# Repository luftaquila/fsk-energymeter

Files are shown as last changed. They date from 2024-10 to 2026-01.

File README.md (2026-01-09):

# Formula Student Korea Electric Energy Meter

<p align="center">
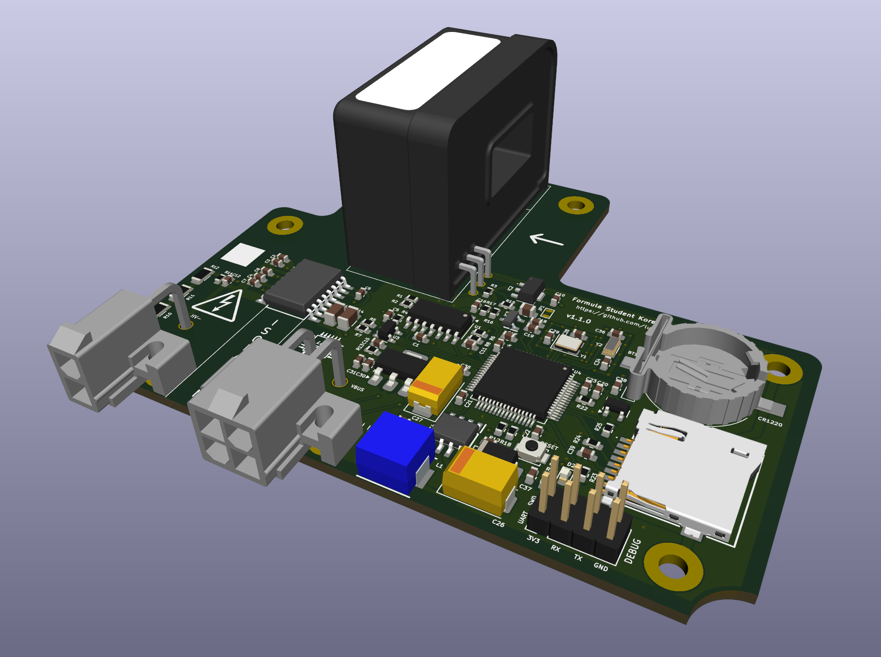
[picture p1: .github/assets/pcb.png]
  
  &ensp;
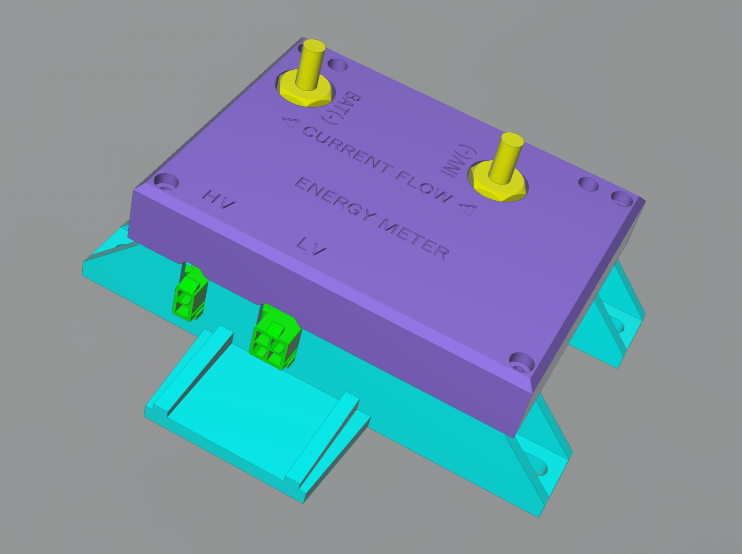
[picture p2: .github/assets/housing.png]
  
</p>

## 0. Features

* 100 Hz data recording
  * HV bus voltage 
  * HV bus current
  * LV supply voltage 
  * Ambient (CPU) temperature
  * Real-world time of each record
* USB Mass Storage data extraction
* Web-based data viewer

## 1. Specifications

| | MIN | TYP | MAX | UNIT |
|:-:|:-:|:-:|:-:|:-:|
| Supply voltage<sup>1</sup> | 6 | | 28 | V |
| Power consumption | | 0.25 | 0.5 | W |
| HV bus voltage | 0 | | 600 | V |
| HV bus voltage resolution | | 0.24 | | V/LSB |
| HV bus current | -750 | | 750 | A |
| HV bus current resolution | | 0.32 | | A/LSB |
| Operational temperature | -10 | | 80 | °C |
| IP rating | | IP 20 | | |
| Startup time | | 550 | | ms |
| Record interval | | 10 | 15 | ms |
| Possible data loss<br>on power brownout | 0 | | 100 | ms |

<sup>1</sup> When powered by USB, the device can startup with a minimum supply voltage of 4.5 V.

## 2. Connectors

> [!NOTE]
> The HV current measurement terminals at the top of the device are standard-pitch M6 brass bolts.

| | LV | HV |
|:-:|:-:|:-:|
| Model | [Molex 5569-04A1 (39291048)](https://www.molex.com/en-us/products/part-detail/39291048) | [Molex 5569-02A1 (39291028)](https://www.molex.com/en-us/products/part-detail/39291028) |
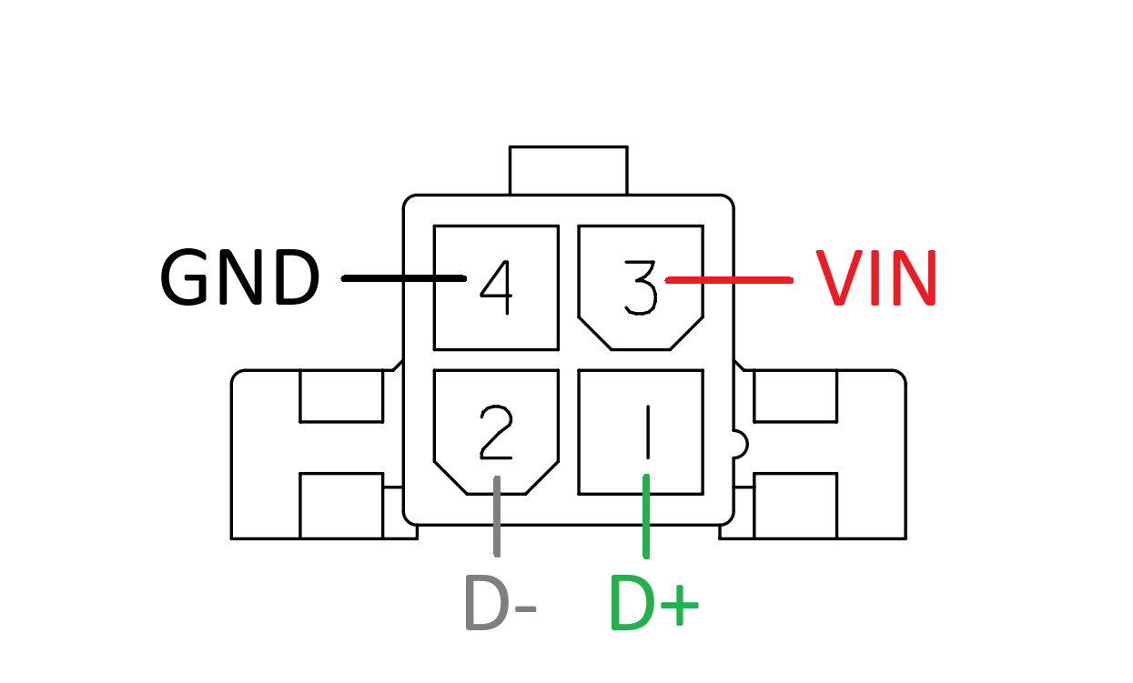
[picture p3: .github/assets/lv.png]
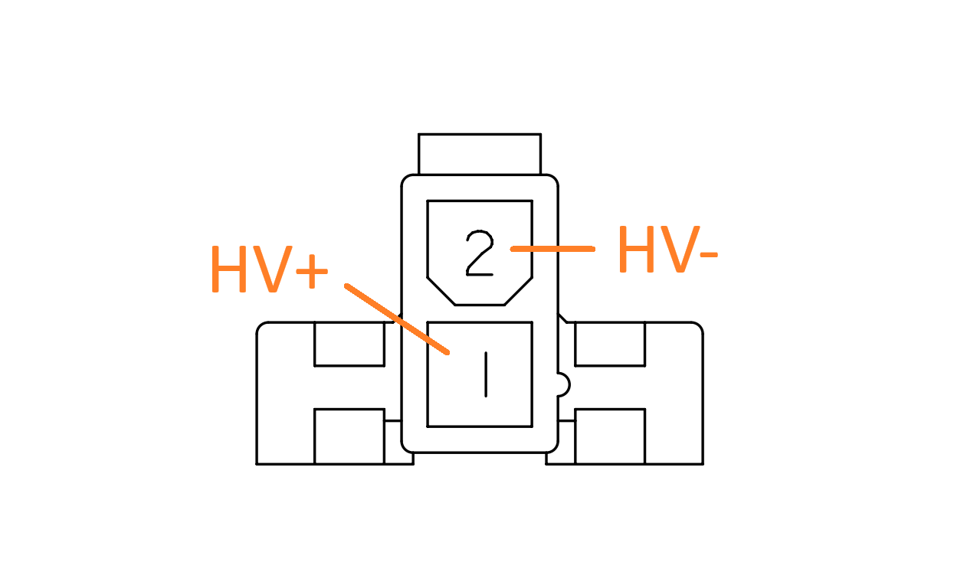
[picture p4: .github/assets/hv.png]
| Image |  |  |
| Mate | [Molex 5557-04R (39012040)](https://www.molex.com/en-us/products/part-detail/39012040) | [Molex 5557-02R (39012020)](https://www.molex.com/en-us/products/part-detail/39012020)  |
| Pinout | 1: `D+` &ensp; 2: `D-`<br>3: `VIN` &ensp; 4: `GND` | 1: `HV+` &ensp; 2: `HV-` |

> [!TIP]
> The crimp terminal for the Molex 5557 Series is [Molex 5556T (39000038)](https://www.molex.com/en-us/products/part-detail/39000038).

### Wiring

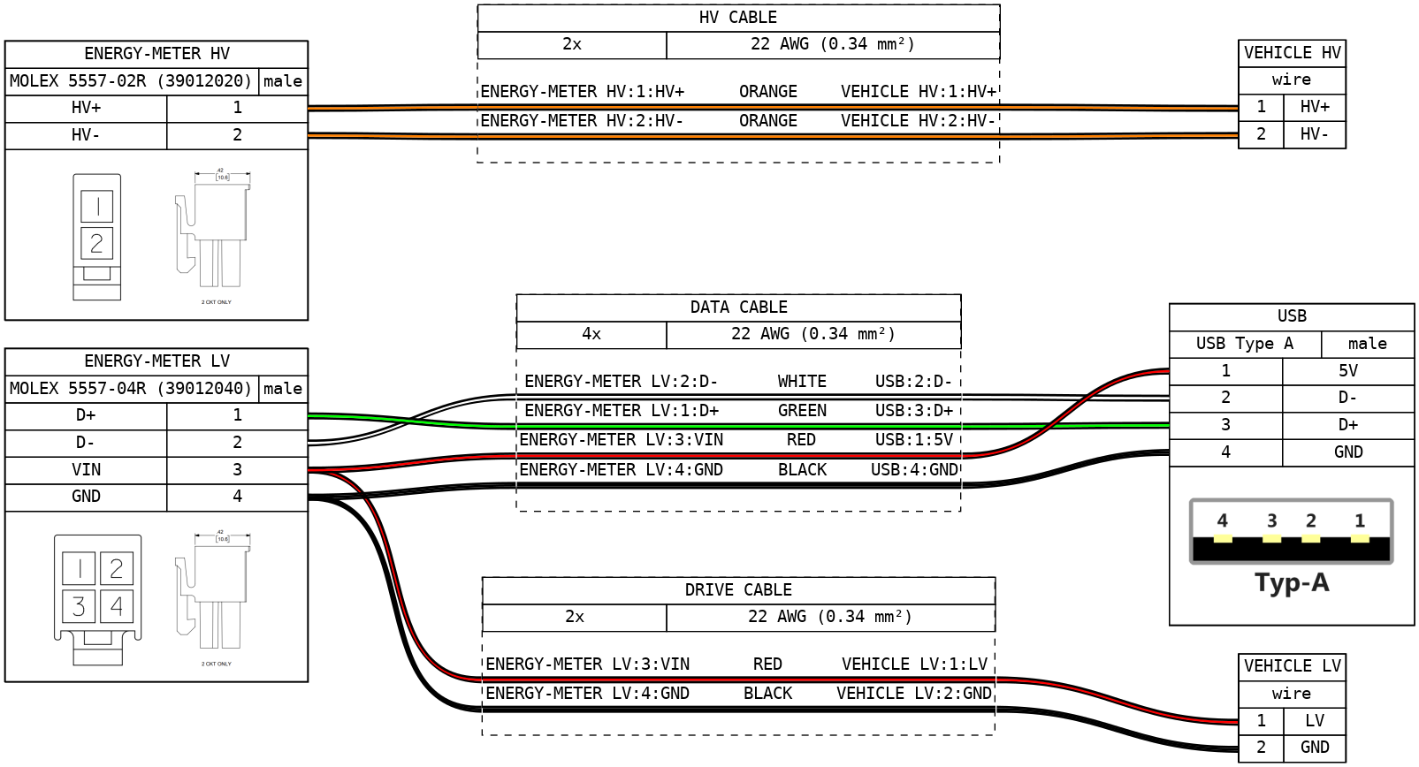
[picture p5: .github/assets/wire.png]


The _data cable_ and the _drive cable_ are two distinct cables.
When driving the vehicle, connect the _drive cable_ to the LV connector of the device.
To extract data, disconnect the _drive cable_ and connect the _data cable_ instead.

> [!CAUTION]
> Misconnection of the pins may cause permanent damage to the device.

> [!TIP]
> The easiest way to make a data cable is to cut a USB cable with Type-A connector on one end.

## 3. Usage

### 3-1. Record data

When driving the vehicle, connect both _HV cable_ and _drive cable_ to the device. The _drive cable_ should supply `VIN >= 6V` to start recording.

Once the device is powered up, it performs a zero calibration of the HV voltage and current. After calibration, it continuously measures data every 10 ms.

The measured data is updated to the file every 100 ms. During the file update, next measurement may be delayed by up to 5 ms.

A new log file is created with each power cycle. Each log file corresponds to a single power session.

> [!IMPORTANT]
> For the precise calibration, make sure that the HV voltage and current are at 0V and 0A until the startup is complete (typically 550 ms).

> [!NOTE]
> The device has an internal clock that tracks real-world time.
> Since the clock drifts over time, synchronize it with the FSK-EEM Viewer after a long period of non-use.
> If the time keeps resetting to `May 12, 2099`, the battery should be replaced.

### 3-2. Extract data

To extract the recorded data from the device, disconnect _drive cable_ and connect _data cable_ instead.
There is no need to disconnect the _HV cable_ during data extraction.

Plug the USB side of the _data cable_ to the PC or smartphone (with a Type-A to C adapter).
The FSK-EEM USB Mass Storage will appear [shortly](https://github.com/luftaquila/fsk-energymeter?tab=readme-ov-file#6-troubleshootings).

The log files are stored in the drive like a common USB memory. Copy the files to your PC.

> [!NOTE]
> The drive is ***read-only***; you cannot edit or delete the stored logs with the file explorer.

### 3-3. View data

Go to the [online viewer](https://fsk-energymeter.luftaquila.io) and open the log file to view a graph of the recorded data, or export it in a human-readable JSON/CSV format.

> [!TIP]
> If there is no Internet connection, download html or executable from the [release](https://github.com/luftaquila/fsk-energymeter/releases/latest) in advance.

### 3-4. Configure the device

In the viewer's Device Configuration section, click `Connect` and select the device to connect.

The device's UID and the current time will be displayed on successful connection.

* `Sync RTC`: Synchronizes the device clock with the host computer.
* `Delete`: Erases ***ALL*** files stored in the device.

Unplug and reconnect the device to see the change after deletion.

> [!WARNING]
> The delete action ***cannot be undone***.

## 4. DIY

### 4.1 Build hardware

1. Download `fsk-energymeter-pcb.zip` from the [latest release](https://github.com/luftaquila/fsk-energymeter/releases/latest) and extract it.
2. Place a JLCPCB PCBA (SMT) order using the GERBER, BOM and CPL files at the *gerbers/* directory.
3. Solder following parts manually to the device after the PCB arrives.
    * [L01Z600S05](https://www.eleparts.co.kr/goods/view?no=261774) Hall sensor
    * [5557-02A1](https://www.eleparts.co.kr/goods/view?no=25304) HV connector
    * [5569-04A1](https://www.eleparts.co.kr/goods/view?no=25303) LV connector
    * [2.54mm 2\*4 debug pin header](https://www.eleparts.co.kr/goods/view?no=12534585)
4. Insert the CR1220 battery and Micro SD card into the PCB.

### 4.2 Upload firmware

1. Download `fsk-energymeter-firmware.zip` from the [latest release](https://github.com/luftaquila/fsk-energymeter/releases/latest) and extract it.
1. Connect `3V3`, `GND`, `SWCLK`, `SWDIO` pins of the ST-Link to the corresponding pins on the device's debug pin header.
1. Run `flash.bat` to flash the release firmware to the device.

### 4.3 3d-print housing

1. Download `fsk-energymeter-3d.zip` from the [latest release](https://github.com/luftaquila/fsk-energymeter/releases/latest) and extract it.
2. 3d-print both `top.stl` and `bottom.stl` files.

### 4.4 Final assembly

1. Prepare 1x busbar, 2x M6 nuts, and 2x `M6*35mm` brass bolts.
    * The busbar and nuts are custom-sized and must be CNC-machined.
        * The recommended material is `C11000` copper alloy.
    * The 3D model of the busbar is at `fsk-energymeter-3d.zip`.
        * Dimensions: `75mm(L) * 12mm(W) * 6mm(H)`.
        * Distance between holes: `57.5mm` (center-to-center).
    * The nuts are standard-pitch M6 hexagonal nuts.
        * Dimensions: `14mm(W) * 16mm(H)`.
2. Prepare 5x `M3*4mm` and 4x `M3*20mm` bolts for PCB and housing assembly.
3. Insert the busbar through the Hall sensor and secure it with the M6 bolts and nuts.
4. Place the PCB-busbar assembly into the housing and assemble the housing and cover.

> [!IMPORTANT]
> The HV current path is through the M6 nuts and the busbar. The M6 bolts are not intended to carry HV current.
> Therefore, the nuts must be thick enough to handle the current and provide sufficient contact area, and tall enough to be exposed above the housing cover.

## 5. Development

> [!NOTE]
> This section is *NOT REQUIRED* in general, and is for developers who want to modify the software on their own.

<details>
<summary>click to expand</summary>

### 5-1. Firmware

#### Prerequisites

1. Clone repository
    ```sh
    git clone https://github.com/luftaquila/fsk-energymeter.git --recursive
    ```

2. Make sure the `arm-none-eabi-gcc`, `openocd` and `make` executables are in the `$PATH`.
    * Common
        * [Arm GNU Toolchain (**AArch32 bare-metal target (arm-none-eabi)**)](https://developer.arm.com/downloads/-/arm-gnu-toolchain-downloads)
    * Windows
        * [OpenOCD for Windows](https://gnutoolchains.com/arm-eabi/openocd/)
        * [Make for Windows](https://gnuwin32.sourceforge.net/packages/make.htm)
    * macOS
        ```sh
        brew install make openocd
        ```
    * Linux
        ```sh
        sudo apt-get install build-essential openocd
        ```

#### Build and upload

```sh
cd fsk-energymeter/device/firmware
make program  # release build
make debug    # debug build
```

### 5-2. Viewer

#### Prerequisites

1. [Node.js](https://nodejs.org/en/download/package-manager) >= v20
2. Clone the repository and install dependencies
    ```sh
    git clone https://github.com/luftaquila/fsk-energymeter.git --recursive
    cd fsk-energymeter/viewer
    npm install
    ```

#### Build and run

```sh 
cd fsk-energymeter/viewer
npm run dev          # development server at http://localhost:9400
npm run build        # production build for Docker image 
npm run build:dev    # production build with no base url
npm run build:single # single file html build
```

</details>

## 6. Troubleshootings

#### 1. FSK-EEM USB Mass Storage takes too long to be mounted
The device only supports USB Full Speed (USB 1.1) spec. It is decades-old technology with a maximum transfer speed of 12 Mbps.
However, in the real world, the actual speed is around 4 Mbps (0.5 MB/s).

When the device is connected to the host PC, the host will try to load the FAT table of the SDMMC.
The FAT32 FAT table is typically a few megabytes, so it will take ~20 seconds to mount.

To reduce the mount time, format SD cards with larger cluster sizes.
The RTC sync or record delete functions will work immediately regardless of this limit.

#### 2. `Web Serial API not supported` error on the FSK-EEM Viewer.

The FSK-EEM Viewer's Device Configuration tab uses the Web Serial API to talk with the device, which has [limited support](https://caniuse.com/?search=Web%20Serial%20API) across the platforms and browsers.

## 7. DISCLAIMER

> [!IMPORTANT]
> 차량기술규정 및 출력제한 위반 여부는 대회장에서 제공하는 공식 에너지미터로만 판단합니다.
> 그 밖의 에너지미터는 제조 공정의 차이 등으로 인해 공식 장치와 측정값이 상이할 수 있음을 반드시 인지해야 합니다.
> 이러한 에너지미터는 대회 중에는 사용할 수 없으며, 차량 제작 시 단순 참고용으로만 활용해야 합니다.

## 8. LICENSE

For non-commercial use only:

```
"THE BEERWARE LICENSE" (Revision 42):
LUFT-AQUILA wrote this project. As long as you retain this notice,
you can do whatever you want with this stuff. If we meet someday,
and you think this stuff is worth it, you can buy me a beer in return.
```

이 저장소의 모든 내용물은 비상업적 용도에 한해 얼마든지 자유롭게 사용할 수 있습니다.\
이 프로젝트가 마음에 든다면, 언젠가 우리가 만나게 되었을 때 맥주 한 잔 사 주세요.

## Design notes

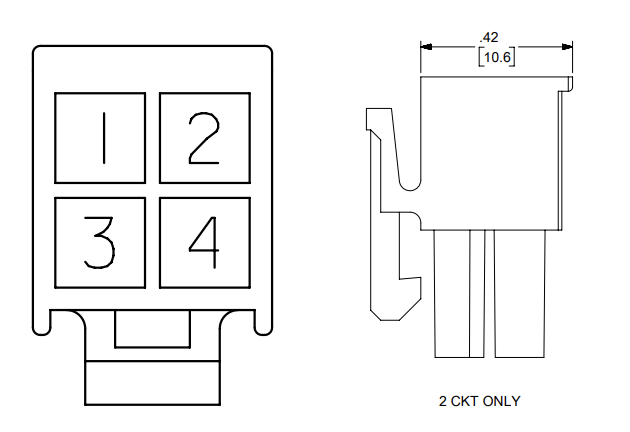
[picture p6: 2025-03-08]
.github/assets/lv-mate.png

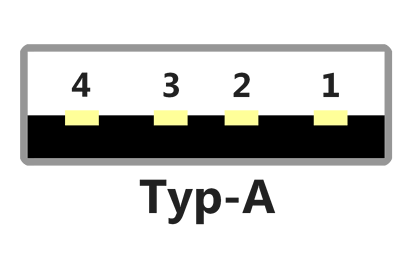
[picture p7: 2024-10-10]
.github/assets/usb.png

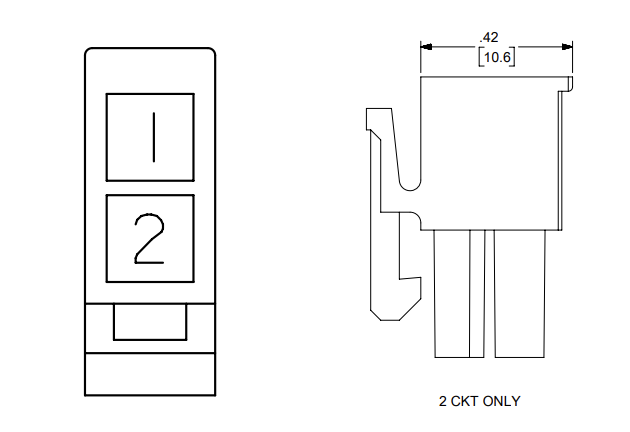
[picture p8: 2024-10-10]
.github/assets/hv-mate.png

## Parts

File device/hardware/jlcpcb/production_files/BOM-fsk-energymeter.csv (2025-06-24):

Comment | Designator | Footprint | LCSC | Quantity
LM2675MX-5.0_NOPB | IC4 | SOIC127P600X175-8N | C123126 | 1
0.1uF | C17,C21,C22,C23,C24,C30,C32,C37,C38,C39,C4,C6,C8 | C_0603_1608Metric | C14663 | 13
100pF | C12 | C_0603_1608Metric | C14858 | 1
1uF | C10,C19,C2 | C_0603_1608Metric | C15849 | 3
1nF | C3,C7 | C_0603_1608Metric | C1588 | 2
20pF | C28,C29,C34,C36 | C_0603_1608Metric | C1648 | 4
330pF | C15,C5 | C_0603_1608Metric | C1664 | 2
0.33uF | C9 | C_0805_2012Metric | C1740 | 1
1uF | C14 | C_1206_3216Metric | C1848 | 1
4.7uF | C35 | C_0603_1608Metric | C19666 | 1
22nF | C1,C11,C16 | C_0603_1608Metric | C21122 | 3
1k | R20 | R_0603_1608Metric | C21190 | 1
AMC3311QDWER | IC1 | SOIC127P1030X265-16N | C22441844 | 1
LED | D2 | LED_0603_1608Metric | C2286 | 1
2k | R1 | R_0603_1608Metric | C22975 | 1
3.3k | R13,R4,R5,R7 | R_0603_1608Metric | C22978 | 4
3.9k | R2 | R_0603_1608Metric | C23018 | 1
68k | R15 | R_0603_1608Metric | C23231 | 1
22 | R18,R19 | R_0603_1608Metric | C23345 | 2
NCP51460SN33T1G | IC3 | SOT96P237X111-3N | C233715 | 1
SS14 | D1 | D_SMA | C2480 | 1
10k | R14,R17,R22,R23,R24,R25,R3 | R_0603_1608Metric | C25804 | 7
100uH | L1 | SMMS0650-101M | C2894722 | 1
560k | R11 | R_1206_3216Metric | C294305 | 1
1M | R10,R9 | R_1206_3216Metric | C2984499 | 2
22k | R16 | R_0603_1608Metric | C31850 | 1
Q13FC13500004 | Y2 | Crystal_SMD_3215-2Pin_3.2x1.5mm | C32346 | 1
BAT54C | D3 | SOT-23 | C37704 | 1
20k | R6,R8 | R_0603_1608Metric | C4184 | 2
LMV324AIDR | U1 | SOIC-14_3.9x8.7mm_P1.27mm | C484732 | 1
430k | R12 | R_1206_3216Metric | C5266168 | 1
TLV9001UIDBVR | U3 | SOT-23-5 | C544301 | 1
10nF | C18,C25 | C_0603_1608Metric | C57112 | 2
AMS1117-3.3 | U5 | AMS1117-3.3 | C6186 | 1
CR1220 | BT1 | S8411-45R_1 | C70381 | 1
78L05G-AB3-R | IC2 | L78L05ABUTR | C71136 | 1
Micro_SD_Card | J4 | TF115BCP9 | C720505 | 1
100uF | C27 | CP_EIA-7343-31_Kemet-D | C7223 | 1
STM32F401RCTx | U4 | LQFP-64_10x10mm_P0.5mm | C74524 | 1
47uF | C26 | CP_EIA-7343-43_Kemet-X | C87110 | 1
X322525MOB4SI | Y1 | Crystal_SMD_3225-4Pin_3.2x2.5mm | C9006 | 1
1nF | C13 | C_1206_3216Metric | C9196 | 1
10uF | C20,C31,C33 | C_0603_1608Metric | C96446 | 3

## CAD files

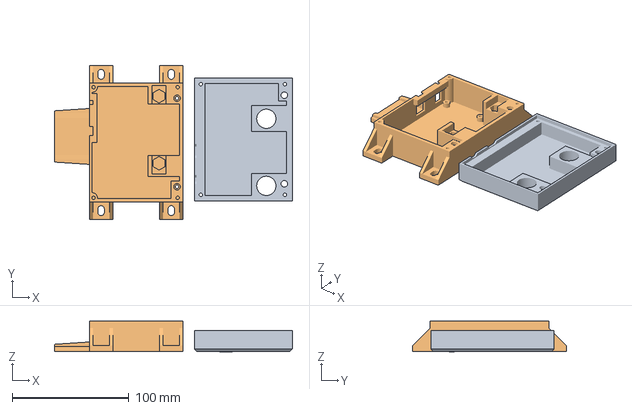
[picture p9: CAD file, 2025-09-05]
device/3d/EM_250620_main.3mf
204.3 x 132.0 x 26.3 mm
Cover_Only_250618.stp
Housing_250629.stp

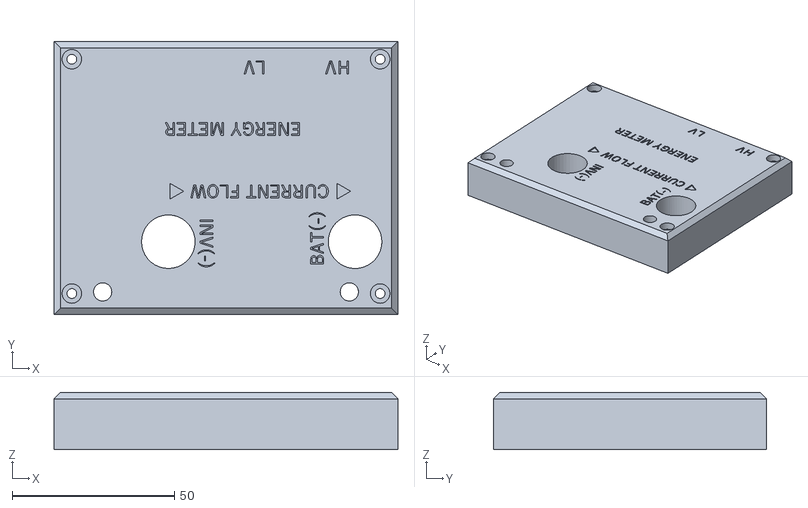
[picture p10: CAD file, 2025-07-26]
device/3d/cover.stl
106.0 x 84.2 x 17.7

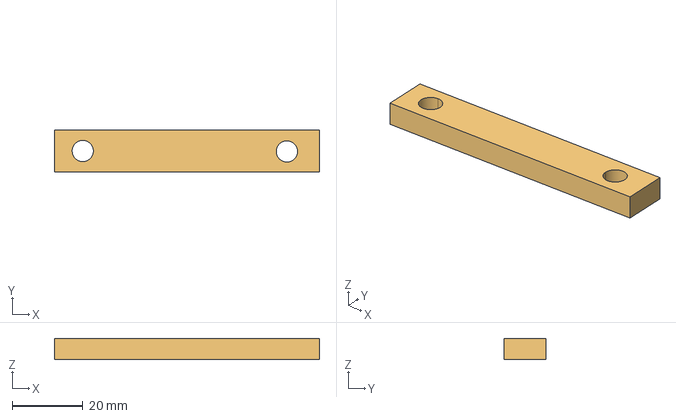
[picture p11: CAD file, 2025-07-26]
device/3d/bus.stp
75.0 x 12.0 x 6.04 mm

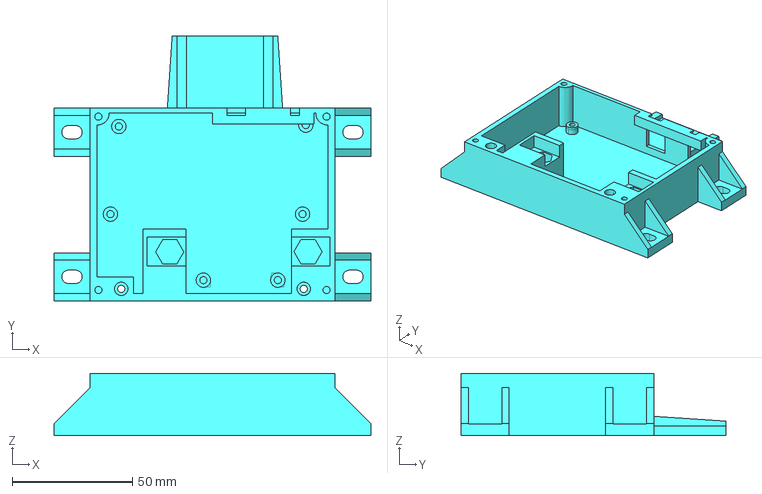
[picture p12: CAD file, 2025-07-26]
device/3d/housing.stp
132.0 x 110.2 x 25.9 mm

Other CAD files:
device/3d/bus.stl
device/3d/housing.stl

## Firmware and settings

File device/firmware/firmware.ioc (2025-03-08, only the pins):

Mcu.UserName=STM32F401RCTx
PA11.Signal=USB_OTG_FS_DM
PA12.Signal=USB_OTG_FS_DP
PA13.Signal=SYS_JTMS-SWDIO
PA14.Signal=SYS_JTCK-SWCLK
PA4.GPIO_Label=ADC_LV_VOLTAGE
PA4.Signal=ADCx_IN4
PA5.GPIO_Label=ADC_5V_REF
PA5.Signal=ADCx_IN5
PA6.GPIO_Label=ADC_HV_CURRENT
PA6.Signal=ADCx_IN6
PA7.GPIO_Label=ADC_HV_VOLTAGE
PA7.Signal=ADCx_IN7
PA9.Signal=USB_OTG_FS_VBUS
PB6.Signal=USART1_TX
PB7.Signal=USART1_RX
PC12.Signal=SDIO_CK
PC13-ANTI_TAMP.GPIO_Label=LED
PC13-ANTI_TAMP.Signal=GPIO_Output
PC14-OSC32_IN.Signal=RCC_OSC32_IN
PC15-OSC32_OUT.Signal=RCC_OSC32_OUT
PC8.Signal=SDIO_D0
PD2.Signal=SDIO_CMD

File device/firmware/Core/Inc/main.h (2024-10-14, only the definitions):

#define LED_Pin GPIO_PIN_13
#define LED_GPIO_Port GPIOC
#define ADC_LV_VOLTAGE_Pin GPIO_PIN_4
#define ADC_LV_VOLTAGE_GPIO_Port GPIOA
#define ADC_5V_REF_Pin GPIO_PIN_5
#define ADC_5V_REF_GPIO_Port GPIOA
#define ADC_HV_CURRENT_Pin GPIO_PIN_6
#define ADC_HV_CURRENT_GPIO_Port GPIOA
#define ADC_HV_VOLTAGE_Pin GPIO_PIN_7
#define ADC_HV_VOLTAGE_GPIO_Port GPIOA

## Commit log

2024-10-02 update: working TinyUSB CDC_MSC example
    [fsk-energymeter.cfg]
2024-10-02 add: schematic template
    [fsk-energymeter.kicad_pcb, fsk-energymeter.kicad_sch]
2024-10-02 improve: caching kicad installation
2024-10-03 update: power, adc, sensor circuits
    [fsk-energymeter.kicad_sch]
2024-10-03 add: peripheral schematics
    [fsk-energymeter.kicad_sch]
2024-10-03 add: power supply capacitors
    [fsk-energymeter.kicad_sch]
2024-10-04 update: complete schematic prototype
    [fsk-energymeter.kicad_sch]
2024-10-04 action: add converted and trimmed png for the schematic
2024-10-04 update: ERC and symbol annotations
    [fsk-energymeter.kicad_sch]
2024-10-05 update: 3.3v reference, power supply, footprints
    [fsk-energymeter.kicad_sch]
2024-10-05 update: initial pcb with netlist
    [fsk-energymeter.kicad_pcb, fsk-energymeter.kicad_sch]
2024-10-06 update: artwork almost done
    [fsk-energymeter.kicad_pcb, fsk-energymeter.kicad_sch]
2024-10-06 update: complete artwork prototype
    [fsk-energymeter.kicad_pcb, fsk-energymeter.kicad_sch]
2024-10-06 fix: isolation distance
    [fsk-energymeter.kicad_pcb]
2024-10-06 fix: SMT issues and resistor values
    [fsk-energymeter-B_Cu.gbr, fsk-energymeter-B_Mask.gbr, fsk-energymeter-B_Paste.gbr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]
2024-10-06 update: replace shortfall parts
    [fsk-energymeter-CuBottom.gbr, fsk-energymeter-CuTop.gbr, fsk-energymeter-EdgeCuts.gbr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]
2024-10-07 update: cleanup tracks, add teardrops
    [fsk-energymeter.kicad_pcb]
2024-10-08 update: use AMC3311 and LM324
    [fsk-energymeter.kicad_sch]
2024-10-09 update: re-artworked PCB with amc3311
    [fsk-energymeter.kicad_pcb, fsk-energymeter.kicad_sch]
2024-10-09 update: HV connector
    [fsk-energymeter-CuBottom.gbr, fsk-energymeter-CuTop.gbr, fsk-energymeter-EdgeCuts.gbr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]
2024-10-10 remove: unused gerbers and BOM/CPL from gitignore
    [fsk-energymeter-B_Cu.gbr, fsk-energymeter-B_Mask.gbr, fsk-energymeter-B_Paste.gbr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]
2024-10-10 add: BOM/CPL
    [BOM-fsk-energymeter.csv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]
2024-10-14 update: add adc ch vrefint, set timer freq, remove usb_detect and fix fatfs sd mode
    [firmware.ioc, main.h]
2024-10-14 update: basic recorder sd and timer manipulation
2024-10-15 add: complete adc calculations
2024-10-15 fix: mode decision voltage value
    [energymeter.c]
2024-10-15 add: debug prints
2024-10-15 improve: error handling
    a
    [energymeter.h, energymeter_record.c]
2024-10-15 improve: force bus enumeration on reset
    [energymeter_usb.c]
2024-10-16 fix: wrong HV voltage divider value
    [energymeter.h]
2024-10-16 fix: make adc_flag volatile to prevent optimized out
    [energymeter.c, energymeter_record.c]
2024-10-17 fix: VBUS voltage detection to judge operation mode
    [energymeter.c]
2024-10-17 fix: HV current calculation
    [energymeter.h, energymeter_record.c]
2024-10-17 port: MSC get capacity and read
2024-10-19 add: USB CDC command prototype
2024-10-19 update: viewer UI prototype
2024-10-21 fix: LMV324AIDR and TLV9001UIDBVR
    [BOM-fsk-energymeter.csv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]
2024-10-21 add: gerbers to release
2024-10-22 fix: RTC date not increasing problem
    [energymeter_usb.c]
2024-10-24 improve: milliseconds in the second line on graph
2024-10-24 add: refresh device time
2024-10-27 fix: wrong current calculation
    [energymeter.h, energymeter_record.c]
2024-10-27 improve: add boot-up calibration
2024-10-27 update: HV voltage scale from 0.01V to 0.1V
2024-10-28 improve: adc error compensation with avg calc
    [energymeter.h, energymeter_record.c]
2024-10-28 improve: adc avg calc structure
2025-01-23 remove: J1 and J3 from POS list
    [CPL-fsk-energymeter.csv, fsk-energymeter-CuBottom.gbr, fsk-energymeter-CuTop.gbr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]
2025-01-24 fix: updated kicad symbols from library
    [fsk-energymeter.kicad_sch]
2025-01-24 fix: kicad svg export
2025-02-03 add: housing stl export pipeline
2025-02-03 add: housing 3d model
2025-02-03 add: housing 3d image
2025-02-04 update: housing 3d model
2025-03-08 refactor: PCB redesign
    * add: LSE crystal
    * replace: HSE from osc to crystal
    * remove: USB pull-up resistor
    * replace: LV connector
    [BOM-fsk-energymeter.csv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]
2025-03-08 update: README connector informations
2025-03-08 update: new housing for redesigned pcb
2025-06-24 update: PCB components
    * disable POS of SW1
    * replace SS15 with SS14 (basic part)
    * replace L78L05ABUTR with 78L05G-AB3-R (basic part)
    [BOM-fsk-energymeter.csv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]
2025-07-26 update: housing 3d models
    [bus.stl, bus.stp, cover.stl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]
2025-09-05 update: readme
    [EM_250620_main.3mf]
2025-09-08 impl: total energy, peak power and current calculation
2025-09-29 update: remove export image button
2025-09-29 add: display peak voltage
2025-09-29 add: reverse current direction
2025-09-29 add: check power limit violation
2025-09-29 add: power limit violation points
2025-10-01 revert: restore graph export button
2025-12-29 update: README assembly guide
2026-01-09 update: remove protocol version and add calibration offset
2026-01-09 fix: calibration values scale
2026-04-02 ci: add GHCR build workflow, improve Dockerfile
    - Multi-stage build: remove node_modules from final image
    - Replace serve with Caddy for static file serving
    - Add multi-arch (amd64/arm64) build workflow with GHCR push
    - Add Caddyfile with SPA fallback and compression
2026-04-07 style: apply Linear design system (Inter font, dark header, flat palette)
    Sync theme changes from formula-student-korea: adopt Linear-inspired
    design tokens, replace gradient header with dark background, remove
    glassmorphism effects, and flatten button/card styles.
2026-10-03 add(viewer): show regen energy and min voltage/current in stats
    - Show regenerated energy next to total energy, e.g. "6.123 kWh (1.234 kWh regen)"
    - Show min values next to peak voltage and current ("max / min")
    - Rename the "Violation" label to "Violations"
    - Fit the stats label column to its content so values have room on one line
2026-10-03 fix(viewer): report violation peaks and periods, add stats tooltips
    - Show each violation's peak value, peak time and period in the alert,
    e.g. "(peak 10.012 kW at 16:20:01.517 / 16:20:01.017 ~ 16:20:01.517)"
    - Report 500 ms violations by the 500 ms average instead of the
    instantaneous power, as the window with the highest average
    - Check 500 ms violations on full 500 ms windows only, and stop
    resetting the window after a violation (the 500 ms cooldown already
    prevents duplicate reports)
    - Report 100 ms violations by the peak power within the 100 ms segment
    - Move the regen energy into a Total Energy tooltip
    (discharge / regen / total, rounded so the lines add up)
    - Collapse the vi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
2026-10-03 fix(viewer): count violation windows by record intervals, sort alerts
    - Average the 500 ms window over (t - 500, t], i.e. 50 records at
    100 Hz instead of 51
    - Measure 100 ms continuous violations from the last record below the
    limit, so 10 records over the limit (100 ms) count as a violation
    - Both follow the energy calculation, where each record stands for the
    interval since the previous record
    - Sort violations by start time so the alert lists them in order
    - Drop the always-true last100msViolationTime check
    - Export the violation type strings as constants
    - Bold the power value in the alert and use "@" for the peak time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
2026-10-03 fix(viewer): use exact integer power in violation checks
    - Keep the 500 ms moving sum and both limit checks in integer power
    (0.01 W, from the 0.1 V / 0.1 A record units). The floating-point
    moving sum carried rounding error across the log, so a power exactly
    at the limit could read as 80.00000000000001 kW and add false 500 ms
    violations.
    - Plot violation markers at the violation value, so 500 ms markers show
    the average shown in the alert instead of the instantaneous power
    - Drop the legend formatters for the violation series; their legend
    rows are hidden
2026-10-03 fix(viewer): keep chart zoom and pan inside the data range
    Every x scale change (wheel, touch, drag select, middle-button pan,
    double click) now goes through one x range function. It keeps the view
    inside the data and at least 50 ms wide (about 5 records at 100 Hz),
    which also keeps zoom clear of epoch-ms float precision limits.
    The wheel plugin no longer tracks the full range itself. Its tracking
    missed the reset when setData kept the same x range (Power Limit or
    Reverse Current while unzoomed), so the next zoom window was taken as
    the full range and later wheel zooms snapped to it.
    Middle-button pan moves by the delta since the last event, so it
    follows back right away after stopping at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
2026-10-03 fix(viewer): restart touch zoom when the fingers change
    The gesture baseline was only reset by touchstart/touchend on the plot
    area. A finger landing on or lifting from the axes or legend changed
    the touch count without a reset, so the view jumped (e.g. ~340x zoom in
    when the second finger landed on an axis, and a snap back when it
    lifted). A touchstart while a one-finger frame was pending drew that
    frame against the new two-finger baseline (~200x zoom out).
    The handler now keys the baseline by touch identifiers and restarts
    from the current view when they change, applying any pending movement
    first. When the view stops at a limit, the gesture continues from there
    instead of building up ove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
2026-10-03 fix(viewer): scale wheel zoom by scroll amount, ignore horizontal scroll
    Each wheel event zoomed by a fixed 25%, so trackpads, which send many
    small events, zoomed far too fast. A deltaY of 0 (horizontal scroll)
    counted as zoom out.
    Pixel deltas now zoom in proportion, with a 100 px notch or any
    line/page step zooming by the configured factor, capped at one step per
    event. Horizontal scroll is left to the page.
2026-10-03 fix(viewer): re-place peak annotations on resize, series toggle and data change
    Annotations were only re-placed when the x range changed, so they kept
    stale positions after a resize, stayed visible after hiding their
    series, and kept the old value after Reverse Current while unzoomed.
2026-10-03 fix(viewer): keep touch gesture going when a finger lifts, handle touchcancel
    touchend on the plot removed the touchmove listener even when fingers
    were still down, so the remaining finger could not pan after a pinch.
    touchcancel was not handled, which left the listener on document and
    blocked page scrolling on later touches.
    touchend and touchcancel are now handled on document, so fingers that
    started outside the plot also end the gesture. While fingers remain,
    the gesture restarts from the current view with them.
2026-10-03 fix(viewer): consume horizontal wheel swipes without zooming
    Returning without preventDefault for deltaY == 0 let horizontal
    trackpad swipes reach the browser, where they can trigger back/forward
    navigation and drop the loaded log. Diagonal swipes with a small deltaY
    still zoomed.
    Every wheel event is consumed again, and events whose horizontal delta
    is at least the vertical one are ignored.
2026-10-03 perf(viewer): skip x scale updates that would not change the view
    uPlot rebuilds every series and redraws on any x setScale, even with
    the same range. Wheel zoom out at full range and panning at a data edge
    did that on every event. The new range is now limited first and
    setScale (and the batch commit) is skipped when it equals the current
    one.
2026-10-04 perf(viewer): keep parsed log data out of deep reactivity
    result was a deep ref, so the processed arrays handed to uPlot were reactive
    proxies and every value read during a redraw went through a proxy trap.
    With a shallowRef uPlot reads plain arrays: zoom redraws on a 1 hour log
    (360k records) get about 30x faster, and calculateMetadata on load, power
    limit toggle and current reversal about 10x faster.
2026-10-04 perf(viewer): stroke chart lines as hairlines on high-DPI screens
    A DevTools trace on a DPR 2 screen showed zoom/pan dropping to ~4 fps with
    page JS at ~1.4 ms per frame: the GPU process spent 200-250 ms per frame
    stroking the 2 device pixel wide lines over thousands of jagged segments.
    The cost only fell off when zoomed in to a few hundred records, while
    1 device pixel lines (hairlines) took ~9 ms even in dense views.
    Lines are now stroked 1 device pixel wide, and the series width is kept by
    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
2026-10-04 fix(viewer): keep hairline copies centered on the point markers
    The repeated hairlines were all shifted right and down, which moved the
    line one device pixel off the data on a DPR 2 screen, so point markers no
    longer sat on its center and looked lopsided. The copies now cover the
    rows and columns the wider stroke would, after uPlot's pixel alignment:
    the same span at DPR 1, 2, 3 and 4, within 0.25 device pixels otherwise.
2026-10-04 add(viewer): include stats cards in exported graph image
    Export Graph now captures the three stats cards above the chart along with
    it, inside a white margin. The image always uses the light theme to match
    the white background: only html2canvas's cloned document switches theme
    (with transitions off), so the page doesn't flash. Info tip icons are hidden
    in the image.
2026-10-04 add(viewer): round y-axis ticks with 0 on a gridline
    Each y axis used to split its visible min/max (plus 5% padding) into nine
    equal intervals, so tick labels were arbitrary values and 0 fell anywhere.
    Now every axis picks a round step (1, 2, 4, 5, 6, 8 x 10^n, and 25 x 10^n
    from 25 up) and starts on a multiple of it, so 0 is always a tick when it
    is in view. The axes still share one interval count, chosen from 6-12 per
    redraw to fill the worst-filled axis best, so their gridlines coincide.
    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
2026-10-04 fix(viewer): keep peak labels inside the plot
    A peak label centered on a peak near the right edge of the plot ran out
    of room and wrapped its text, and near the left edge it covered the
    y-axis labels. The label now stays inside the plot without wrapping, and
    its arrow slides along the bottom edge to stay over the peak.

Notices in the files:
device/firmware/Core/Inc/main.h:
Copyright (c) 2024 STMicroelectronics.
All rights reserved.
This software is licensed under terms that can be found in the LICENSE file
